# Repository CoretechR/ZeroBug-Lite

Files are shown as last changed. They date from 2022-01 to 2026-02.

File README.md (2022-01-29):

# ZeroBug Lite

Zerobug Lite is a minimalistic version of the ZeroBug Hexapod robot. By porting the microcontroller's features to Python, the robot can be fully controlled with only the Rasbperry Pi and an updated PCB.

This is a somewhat experimental build. Use at your own risk!

For CAD files, see the original project: https://github.com/CoretechR/ZeroBug

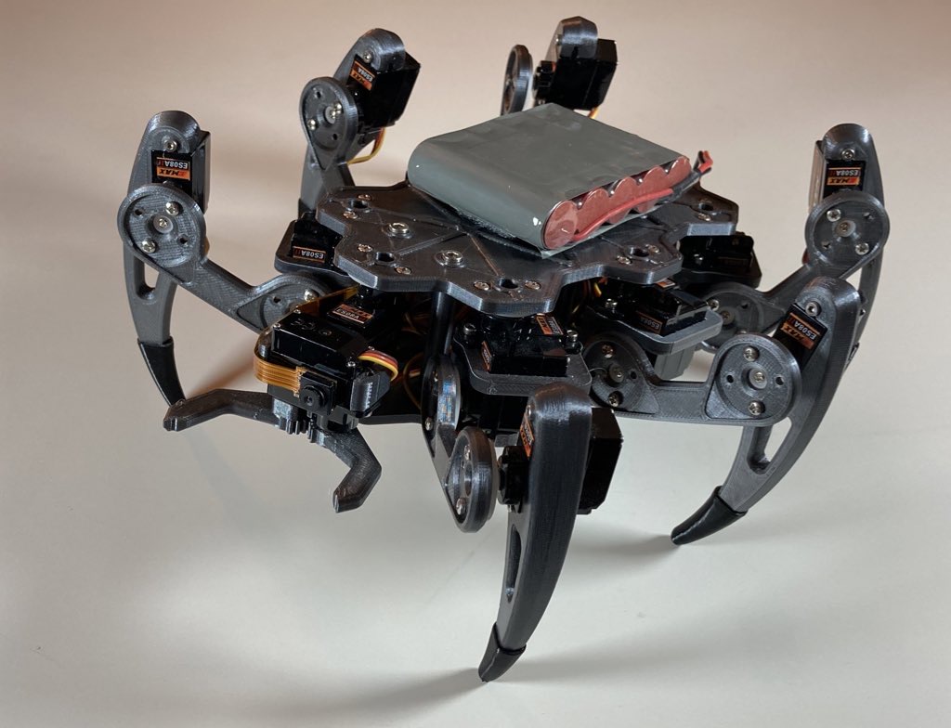
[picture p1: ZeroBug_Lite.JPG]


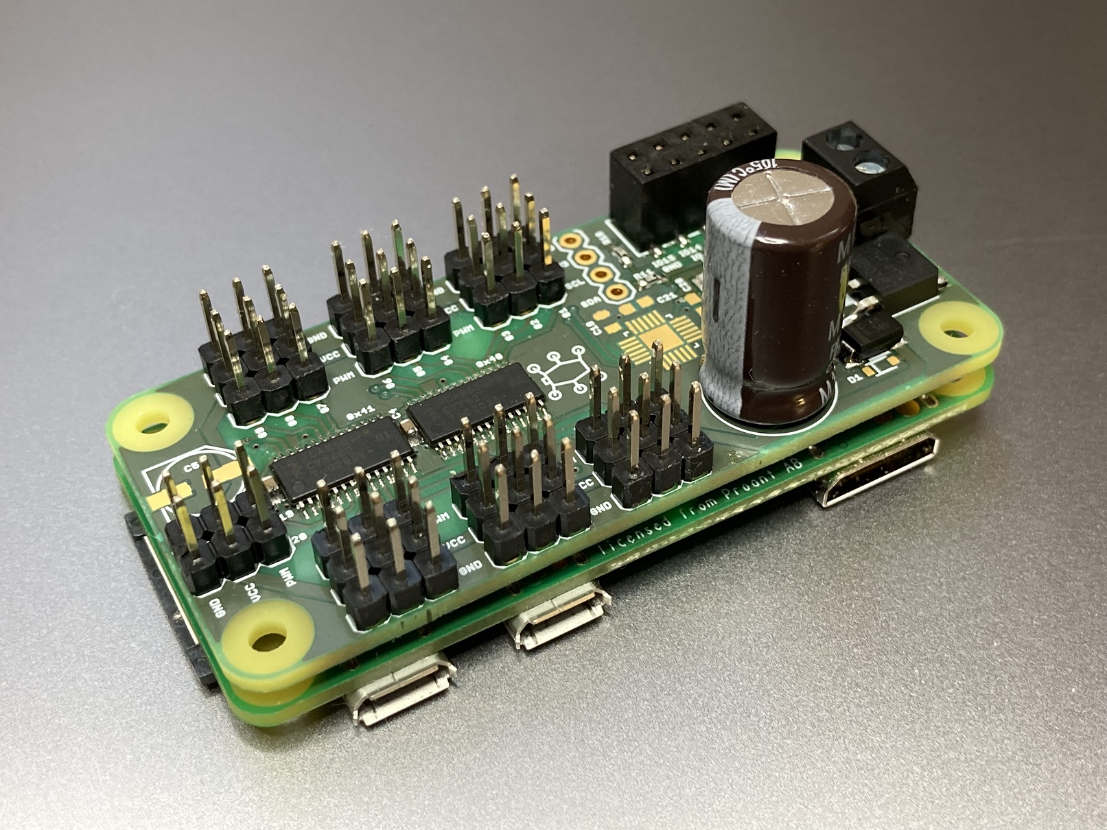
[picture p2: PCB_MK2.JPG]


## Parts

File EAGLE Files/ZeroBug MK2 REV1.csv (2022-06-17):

Qty | Value | Device | Package | Parts | Description | DATASHEET-URL | GENDER | IR | MPN | OC_FARNELL | OC_NEWARK | PACKAGE | PACKAGING | PART-NUMBER | PINS | PROD_ID | ROWS | SUPPLIER | TYPE | VALUE | WE-NUMBER
1 |  | 6103XX21821_61031021821 | 61031021821 | J23 | WR-PHD 2.54 mm SMT Dual Socket Header (Reel) | https://katalog.we-online.com/em/datasheet/61031021821.pdf | Socket Header | 3A |  |  |  |  | Tape and Reel with Cap | 61031021821 | 10 |  | Dual |  | Straight Type 2 |  | 61031021821
20 |  | CONN_03 | 1X03 | J3, J4, J5, J6, J7, J8, J9, J10, J11, J12, J13, J14, J15, J16, J17, J18, J19, J20, J21, J22 | Multi connection point. Often used as Generic Header-pin footprint for 0.1 inch spaced/style header connections |  |  |  |  |  |  |  |  |  |  | XXX-00000 |  |  |  | 455-1750-1-ND
1 |  | CPOL-USE5-10.5 | E5-10,5 | C6 | POLARIZED CAPACITOR, American symbol
2 |  | PCA9685 | TSSOP28 | U1, U2 | PCA9685 - 16 Channel 12-Bit I2C PWM Controller
1 |  | TERMBLOCK_1X2 | TERMBLOCK_1X2-3.5MM | J1 | 3.5mm Terminal block
2 | 0.1uF | 0.1UF-0603-25V-(+80/-20%) | 0603 | C20, C21 | 0.1µF ceramic capacitors |  |  |  |  |  |  |  |  |  |  | CAP-00810 |  |  |  | 0.1uF
1 | 1.0uF | 1.0UF-0805-25V-(+80/-20%) | 0805 | C2 | 1µF ceramic capacitors |  |  |  |  |  |  |  |  |  |  | CAP-11625 |  |  |  | 1.0uF
1 | 100uF | 100UF-POLAR-25V-20%(ELEC) | PANASONIC_D | C5 | 100µF polarized capacitors |  |  |  |  |  |  |  |  |  |  | CAP-12547 |  |  |  | 100uF
2 | 10k | 10KOHM-0603-1/10W-1% | 0603 | R10, R11 | 10kO resistor |  |  |  |  |  |  |  |  |  |  | RES-00824 |  |  |  | 10k
1 | 10nF | 47PF-0603-50V-5% | 0603 | C17 | 47pF ceramic capacitors |  |  |  |  |  |  |  |  |  |  | CAP-08913 |  |  |  | 47pF
2 | 10uF | 1.0UF-0805-25V-(+80/-20%) | 0805 | C1, C4 | 1µF ceramic capacitors |  |  |  |  |  |  |  |  |  |  | CAP-11625 |  |  |  | 1.0uF
1 | 1X4-BIG | 1X4-BIG | 1X04-BIG | CN1 | 4-pin connector
1 | 2.2uF | 1.0UF-0805-25V-(+80/-20%) | 0805 | C18 | 1µF ceramic capacitors |  |  |  |  |  |  |  |  |  |  | CAP-11625 |  |  |  | 1.0uF
1 | 4.7uF | 1.0UF-0805-25V-(+80/-20%) | 0805 | C3 | 1µF ceramic capacitors |  |  |  |  |  |  |  |  |  |  | CAP-11625 |  |  |  | 1.0uF
1 | AOD417 | MOSFET-PTO252 | TO252 | Q1 | P-Channel Mosfet
1 | BAT20J | DIODE-SCHOTTKY-BAT20J | SOD-323 | D1 | Schottky diodes in SFE's production catalog |  |  |  |  |  |  |  |  |  |  | DIO-11623 |  |  |  | BAT20J
1 | CDBA340L-HF | DIODE-DO-214AC | DO-214AC | D2 | DIODE
1 | MCP1826S-5002E/DB | MCP1825S-5002E/DB | SOT230P700X180-4N | U4 | IC, LDO, 5.0V, 500MA |  |  |  | MCP1825S-5002E/DB | 1578407 | 26M9964 | SOT-223-3 |  |  |  |  |  | Microchip
1 | MPU-6050-1 | MPU-6050-1 | QFN-24-4MM2 | U$2

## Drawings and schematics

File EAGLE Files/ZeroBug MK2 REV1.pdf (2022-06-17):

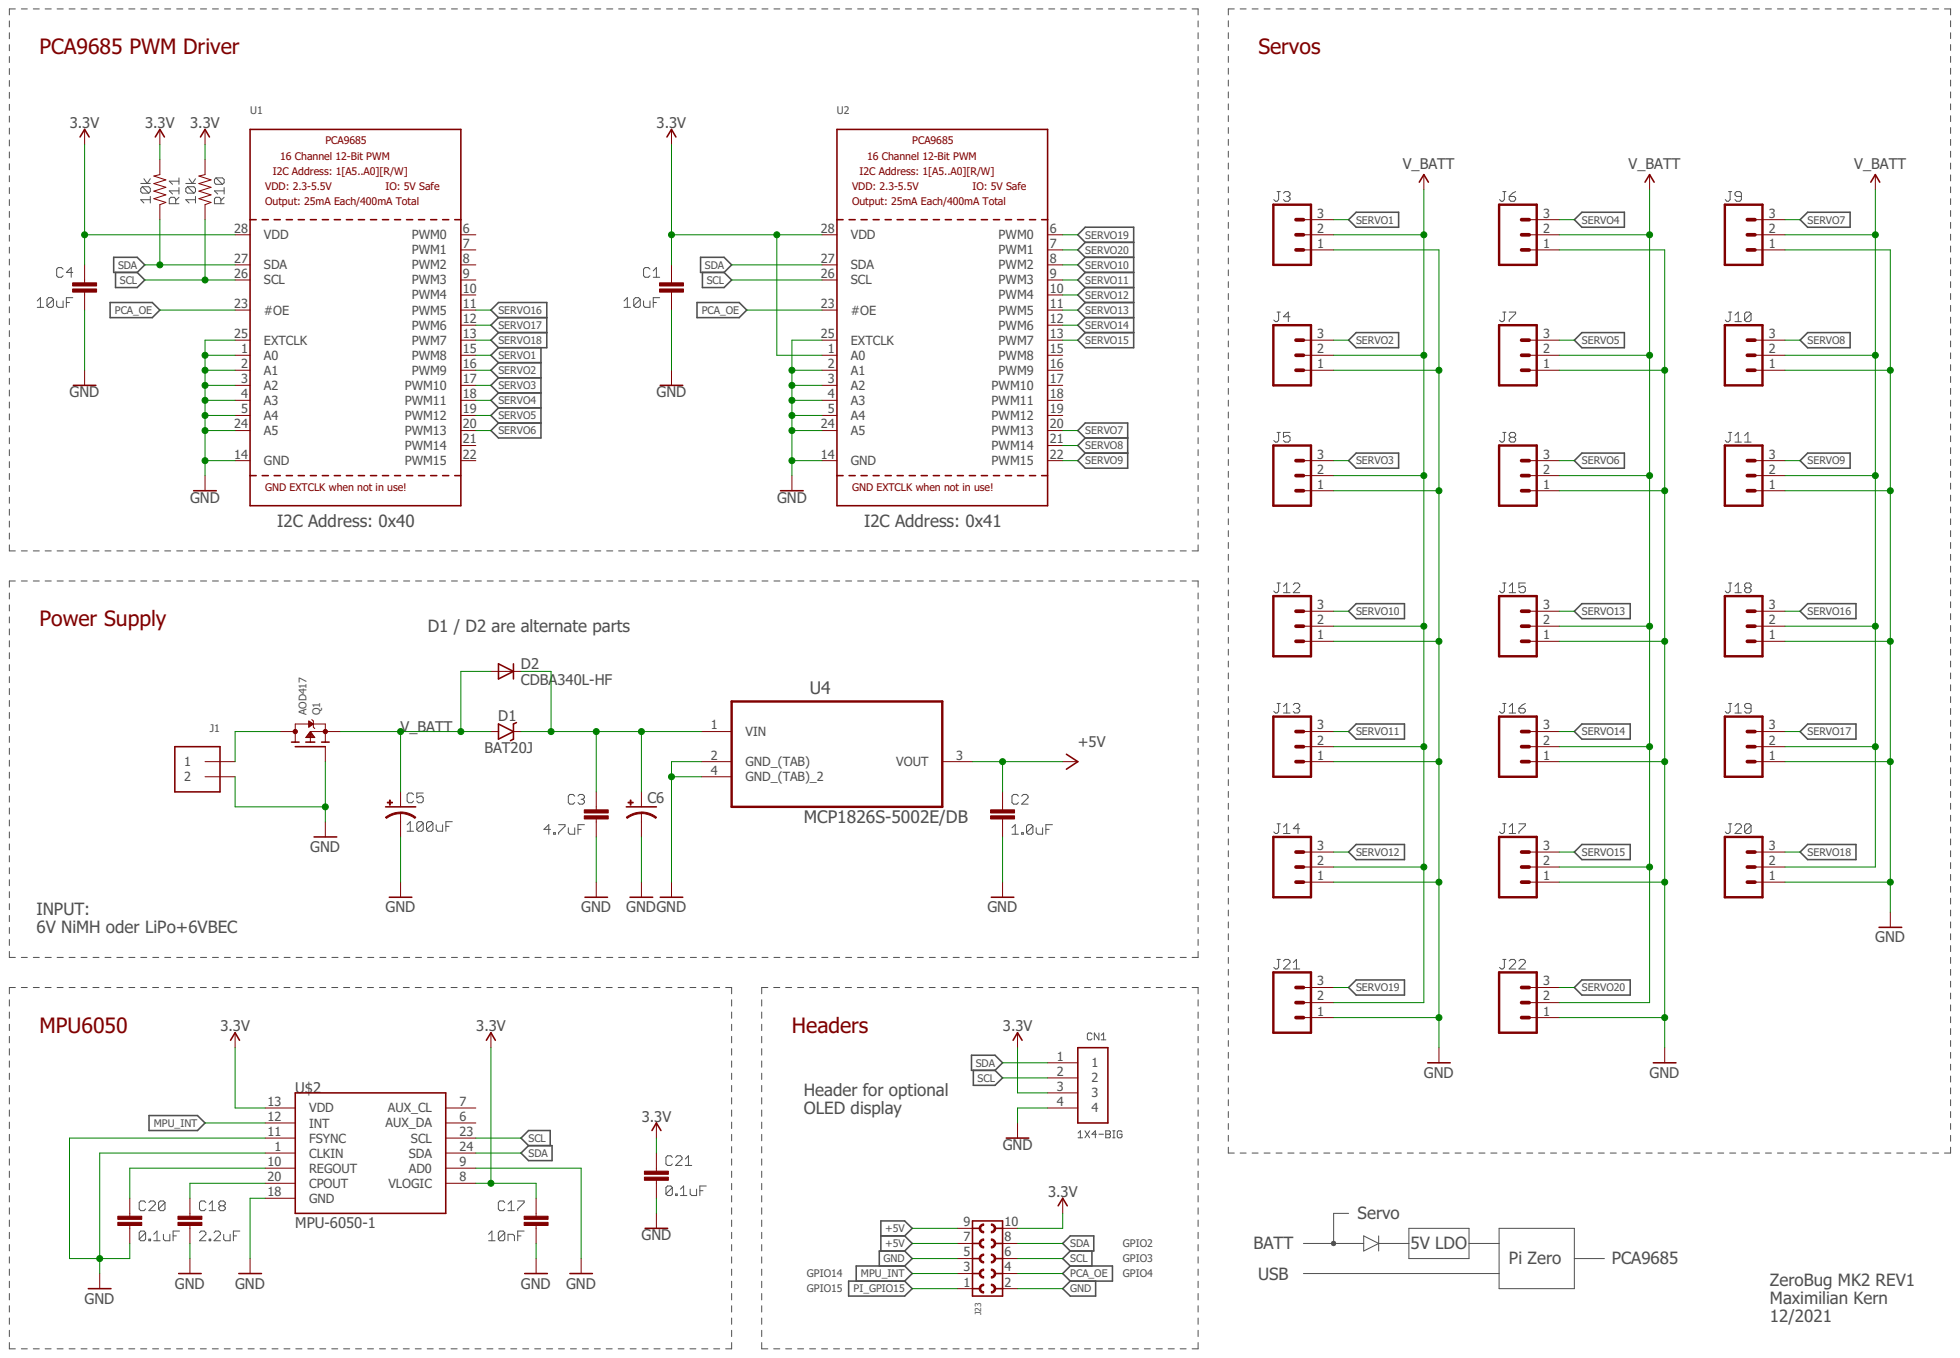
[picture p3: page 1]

GND EXTCLK when not in use!

INPUT: 6V NiMH oder LiPo+6VBEC

Pi Zero Servo BATT

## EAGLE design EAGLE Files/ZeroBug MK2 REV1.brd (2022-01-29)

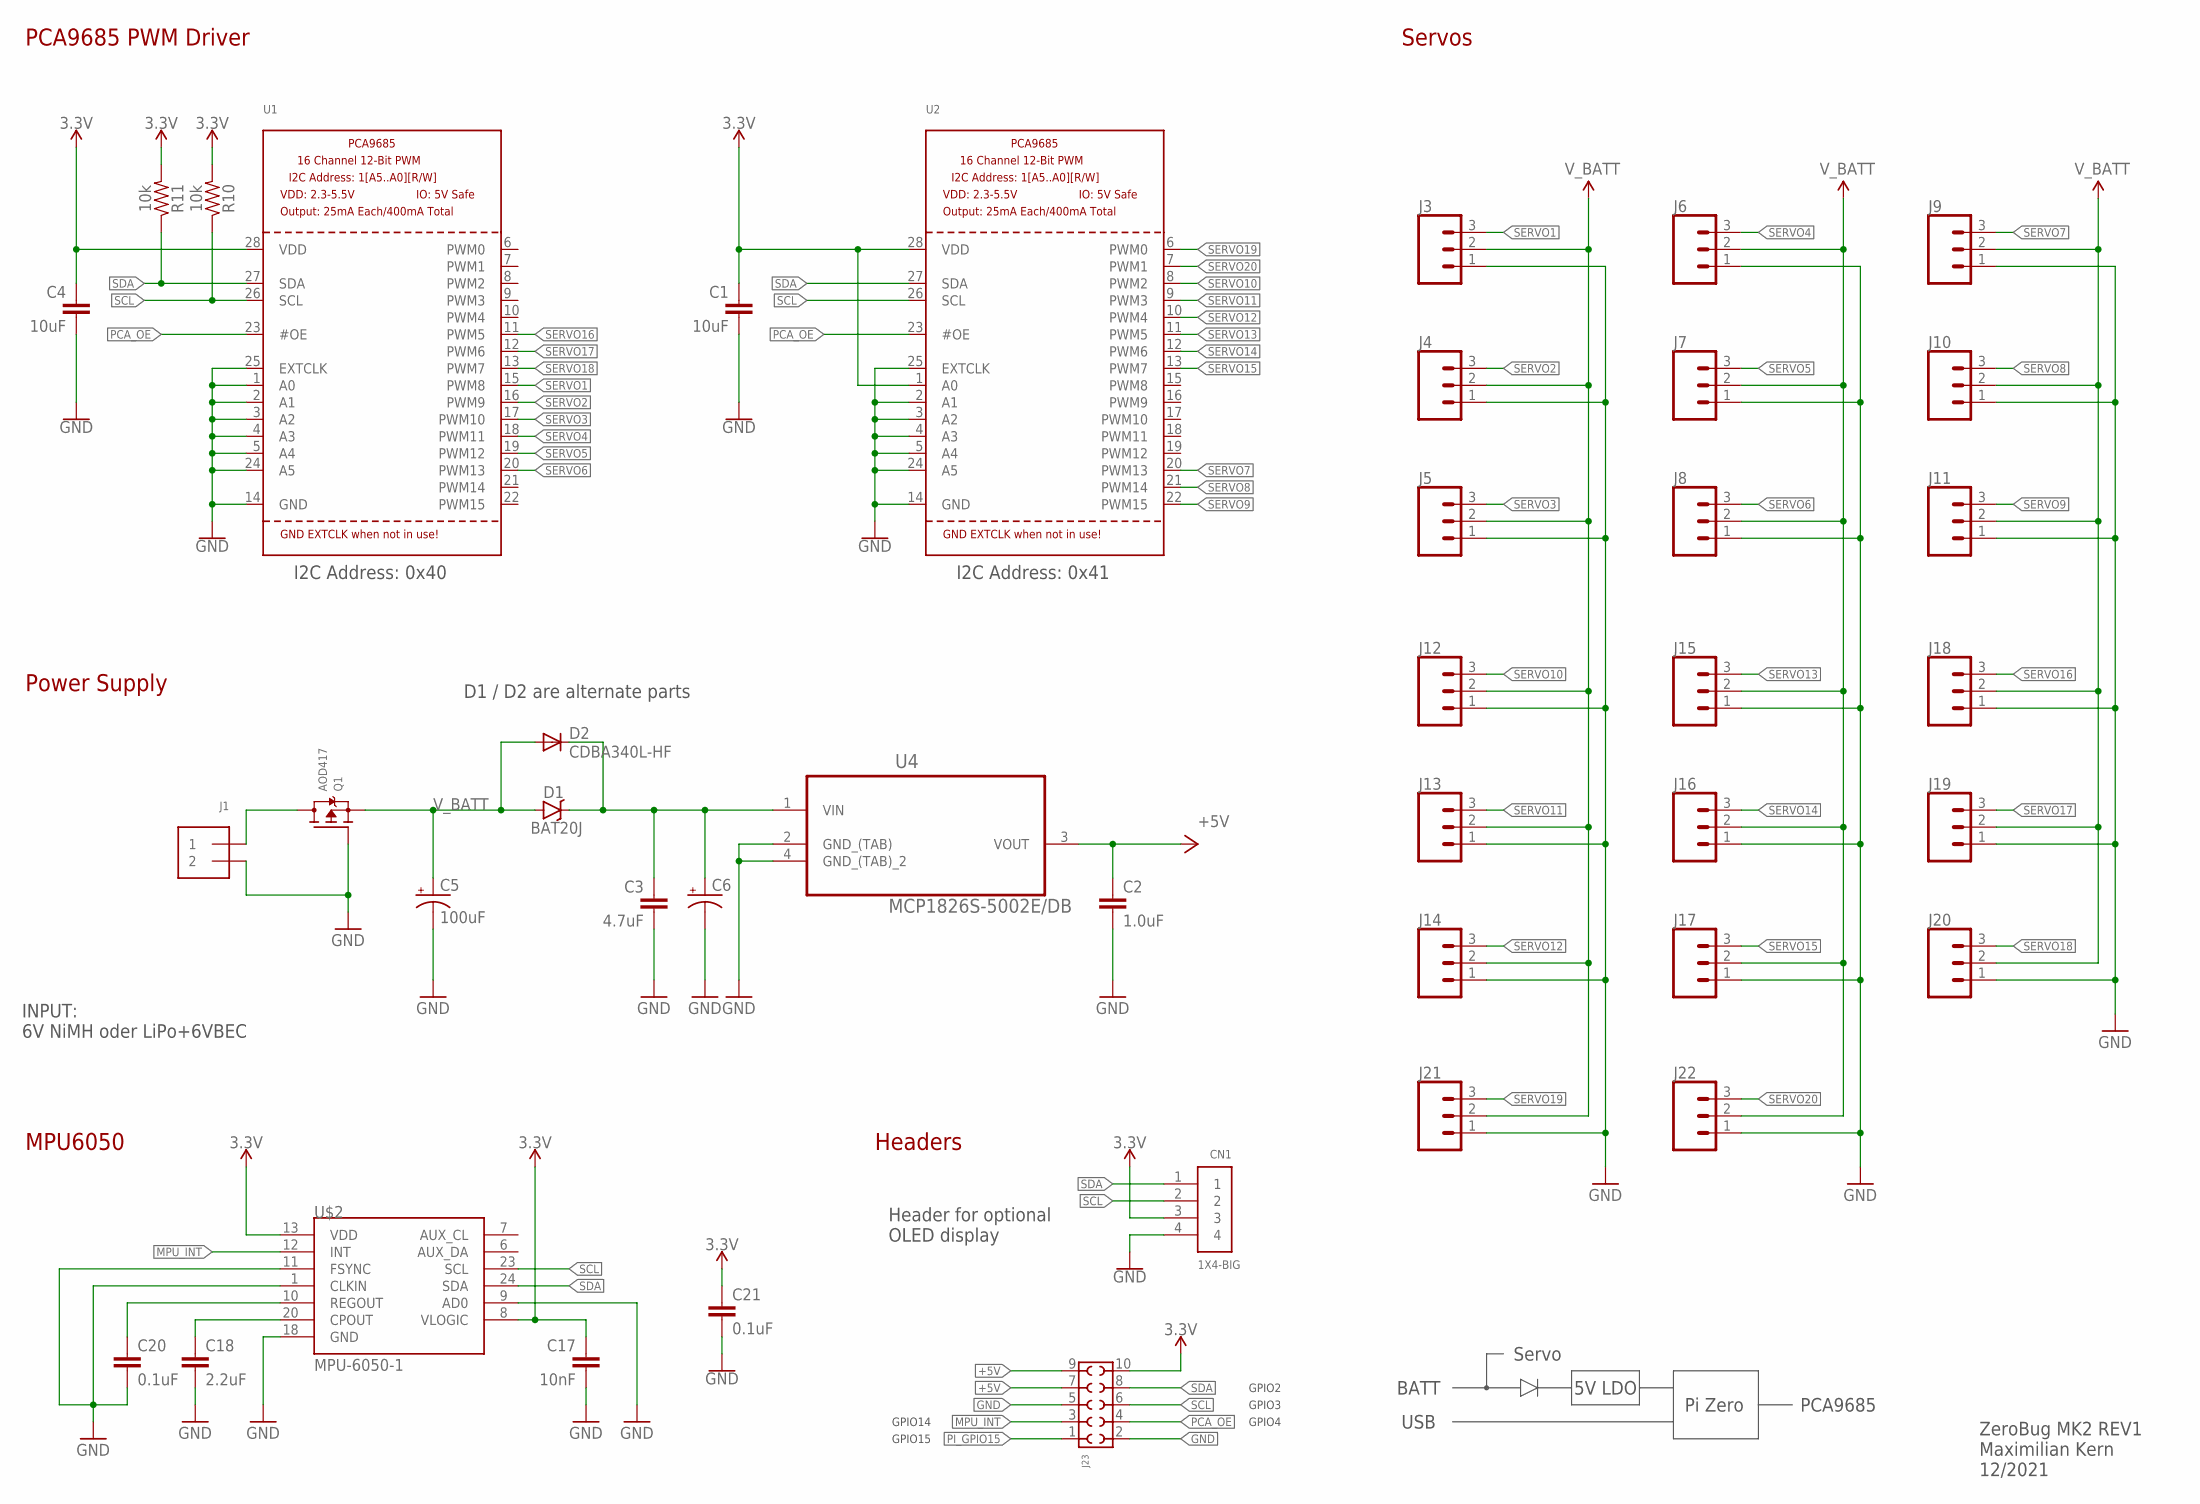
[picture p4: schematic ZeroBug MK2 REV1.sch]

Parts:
C1, C4: 10uF; 0805
C2: 1.0uF; 0805
C3: 4.7uF; 0805
C5: 100uF; PANASONIC_D
C6: CPOL-USE5-10.5; E5-10,5
C17: 10nF; 0603
C18: 2.2uF; 0805
C20, C21: 0.1uF; 0603
CN1: 1X4-BIG; 1X04-BIG
D1: BAT20J; SOD-323
D2: CDBA340L-HF; DO-214AC
J1: TERMBLOCK_1X2; TERMBLOCK_1X2-3.5MM
J3, J4, J5, J6, J7, J8, J9, J10, J11, J12, J13, J14, J15, J16, J17, J18, J19, J20, J21, J22: CONN_03; 1X03
J23: 6103XX21821_61031021821; 61031021821
Q1: AOD417; TO252
R10, R11: 10k; 0603
U1, U2: PCA9685; TSSOP28
U4: MCP1826S-5002E/DB; SOT230P700X180-4N
U$2: MPU-6050-1; QFN-24-4MM2

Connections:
3.3V: C1.1, C4.1, C17.1, C21.1, CN1.3, J23.10, R10.2, R11.2, U1.28 (VDD), U2.1 (A0), U2.28 (VDD), U$2.8 (VLOGIC), U$2.13 (VDD)
+5V: C2.1, J23.7, J23.9, U4.3 (VOUT)
GND: C1.2, C2.2, C3.2, C4.2, C5.-, C6.-, C17.2, C18.2, C20.2, C21.2, CN1.4, J1.2, J3.1, J4.1, J5.1, J6.1, J7.1, J8.1, J9.1, J10.1, J11.1, J12.1, J13.1, J14.1, J15.1, J16.1, J17.1, J18.1, J19.1, J20.1, J21.1, J22.1, J23.2, J23.5, Q1.1 (G), U1.1 (A0), U1.2 (A1), U1.3 (A2), U1.4 (A3), U1.5 (A4), U1.14 (GND), U1.24 (A5), U1.25 (EXTCLK), U2.2 (A1), U2.3 (A2), U2.4 (A3), U2.5 (A4), U2.14 (GND), U2.24 (A5), U2.25 (EXTCLK), U4.2 (GND_(TAB)), U4.4 (GND_(TAB)_2), U$2.1 (CLKIN), U$2.9 (AD0), U$2.11 (FSYNC), U$2.18 (GND)
MPU_INT: J23.3, U$2.12 (INT)
unnamed: C3.1, C6.+, D1.C, D2.C, U4.1 (VIN)
unnamed: J1.1, Q1.3 (D)
unnamed: C18.1, U$2.20 (CPOUT)
unnamed: C20.1, U$2.10 (REGOUT)
PCA_OE: J23.4, U1.23 (#OE), U2.23 (#OE)
PI_GPIO15: J23.1
SCL: CN1.2, J23.6, R10.1, U1.26 (SCL), U2.26 (SCL), U$2.23 (SCL)
SDA: CN1.1, J23.8, R11.1, U1.27 (SDA), U2.27 (SDA), U$2.24 (SDA)
SERVO1: J3.3, U1.15 (PWM8)
SERVO2: J4.3, U1.16 (PWM9)
SERVO3: J5.3, U1.17 (PWM10)
SERVO4: J6.3, U1.18 (PWM11)
SERVO5: J7.3, U1.19 (PWM12)
SERVO6: J8.3, U1.20 (PWM13)
SERVO7: J9.3, U2.20 (PWM13)
SERVO8: J10.3, U2.21 (PWM14)
SERVO9: J11.3, U2.22 (PWM15)
SERVO10: J12.3, U2.8 (PWM2)
SERVO11: J13.3, U2.9 (PWM3)
SERVO12: J14.3, U2.10 (PWM4)
SERVO13: J15.3, U2.11 (PWM5)
SERVO14: J16.3, U2.12 (PWM6)
SERVO15: J17.3, U2.13 (PWM7)
SERVO16: J18.3, U1.11 (PWM5)
SERVO17: J19.3, U1.12 (PWM6)
SERVO18: J20.3, U1.13 (PWM7)
SERVO19: J21.3, U2.6 (PWM0)
SERVO20: J22.3, U2.7 (PWM1)
V_BATT: C5.+, D1.A, D2.A, J3.2, J4.2, J5.2, J6.2, J7.2, J8.2, J9.2, J10.2, J11.2, J12.2, J13.2, J14.2, J15.2, J16.2, J17.2, J18.2, J19.2, J20.2, J21.2, J22.2, Q1.2 (S)

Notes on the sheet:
ZeroBug MK2 REV1 Maximilian Kern 12/2021
INPUT: 6V NiMH oder LiPo+6VBEC
5V LDO
Pi Zero
Servo
BATT
USB
PCA9685
MPU6050
Servos
PCA9685 PWM Driver
Headers
Power Supply
GPIO4
GPIO2
GPIO3
GPIO14
GPIO15
I2C Address: 0x40
I2C Address: 0x41
D1 / D2 are alternate parts
Header for optional OLED display

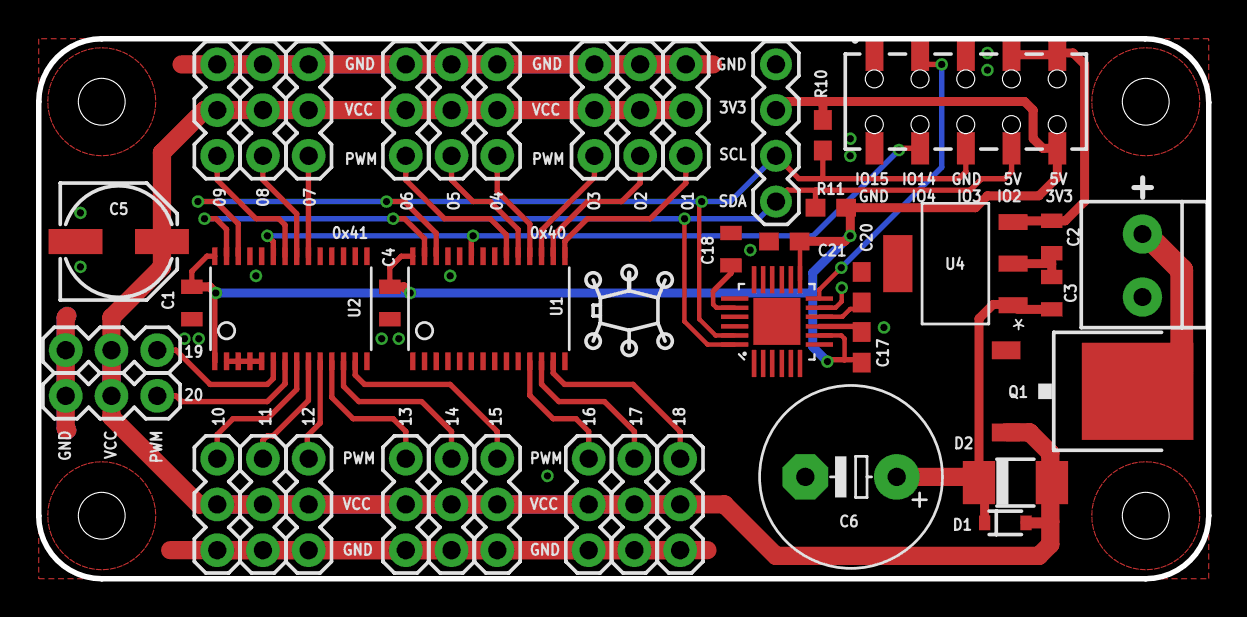
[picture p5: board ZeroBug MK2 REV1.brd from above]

Board: 2 copper layers, 65.0 x 30.0 mm, 42 parts (0 on the bottom side), 32 nets.

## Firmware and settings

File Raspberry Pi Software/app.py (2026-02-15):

from vector import *
from aiohttp import web
import socketio
import asyncio
from gpiozero import CPUTemperature
import pygame
import os
import math
import time
from board import SCL, SDA
import busio
import RPi.GPIO as GPIO

# Import the PCA9685 module.
from adafruit_motor import servo
from adafruit_pca9685 import PCA9685

# constants
SERVOMIN = 604.0 # This is the 'minimum' pulse length count (out of 4096)
SERVOMAX = 2260.0 # This is the 'maximum' pulse length count (out of 4096)
SERVO_FREQ = 50 # Analog servos run at ~50 Hz updates
PCA_OE = 4 # PCA Output Enable Pin

# global variables
powerup = False;
powerdown = False;

# Create the I2C bus interface.
i2c_bus = busio.I2C(SCL, SDA, frequency=400)

# Create a simple PCA9685 class instance.
pca_a = PCA9685(i2c_bus, address=0x40)
pca_b = PCA9685(i2c_bus, address=0x41)

# Set the PWM frequency to 50hz.
pca_a.frequency = SERVO_FREQ
pca_b.frequency = SERVO_FREQ
# Set twice because of some i2c error stuff
time.sleep(0.1);
pca_a.frequency = SERVO_FREQ
pca_b.frequency = SERVO_FREQ

clawOpen = False;
clawClose = False;
clawPos = 0.0;

servos = [None] * 20
servos[0] = servo.Servo(pca_a.channels[8],  actuation_range = 300, min_pulse=SERVOMIN, max_pulse=SERVOMAX)
servos[1] = servo.Servo(pca_a.channels[9],  actuation_range = 300, min_pulse=SERVOMIN, max_pulse=SERVOMAX)
servos[2] = servo.Servo(pca_a.channels[10], actuation_range = 300, min_pulse=SERVOMIN, max_pulse=SERVOMAX)

servos[3] = servo.Servo(pca_a.channels[11],  actuation_range = 300, min_pulse=SERVOMIN, max_pulse=SERVOMAX)
servos[4] = servo.Servo(pca_a.channels[12],  actuation_range = 300, min_pulse=SERVOMIN, max_pulse=SERVOMAX)
servos[5] = servo.Servo(pca_a.channels[13], actuation_range = 300, min_pulse=SERVOMIN, max_pulse=SERVOMAX)

servos[6] = servo.Servo(pca_b.channels[13],  actuation_range = 300, min_pulse=SERVOMIN, max_pulse=SERVOMAX)
servos[7] = servo.Servo(pca_b.channels[14],  actuation_range = 300, min_pulse=SERVOMIN, max_pulse=SERVOMAX)
servos[8] = servo.Servo(pca_b.channels[15], actuation_range = 300, min_pulse=SERVOMIN, max_pulse=SERVOMAX)

servos[9] = servo.Servo(pca_b.channels[2],  actuation_range = 300, min_pulse=SERVOMIN, max_pulse=SERVOMAX)
servos[10] = servo.Servo(pca_b.channels[3],  actuation_range = 300, min_pulse=SERVOMIN, max_pulse=SERVOMAX)
servos[11] = servo.Servo(pca_b.channels[4], actuation_range = 300, min_pulse=SERVOMIN, max_pulse=SERVOMAX)

servos[12] = servo.Servo(pca_b.channels[5],  actuation_range = 300, min_pulse=SERVOMIN, max_pulse=SERVOMAX)
servos[13] = servo.Servo(pca_b.channels[6],  actuation_range = 300, min_pulse=SERVOMIN, max_pulse=SERVOMAX)
servos[14] = servo.Servo(pca_b.channels[7], actuation_range = 300, min_pulse=SERVOMIN, max_pulse=SERVOMAX)

servos[15] = servo.Servo(pca_a.channels[5],  actuation_range = 300, min_pulse=SERVOMIN, max_pulse=SERVOMAX)
servos[16] = servo.Servo(pca_a.channels[6],  actuation_range = 300, min_pulse=SERVOMIN, max_pulse=SERVOMAX)
servos[17] = servo.Servo(pca_a.channels[7], actuation_range = 300, min_pulse=SERVOMIN, max_pulse=SERVOMAX)

servos[18] = servo.Servo(pca_b.channels[0],  actuation_range = 300, min_pulse=SERVOMIN, max_pulse=SERVOMAX)
servos[19] = servo.Servo(pca_b.channels[1], actuation_range = 300, min_pulse=SERVOMIN, max_pulse=SERVOMAX)


# Initialize routines
sio = socketio.AsyncServer()
app = web.Application()
sio.attach(app)
loop = asyncio.get_event_loop()
pygame.display.init()

# enable PCA (LOW means On)
GPIO.setmode(GPIO.BCM)
GPIO.setup(PCA_OE, GPIO.OUT)
GPIO.output(PCA_OE, GPIO.LOW)

# setup hexapod parameters
tripodGait = [[0 for x in range(6)] for y in range(120)] 
waveGait = [[0 for x in range(6)] for y in range(120)] 

Hex = gaitEngine()

jX = 0  # (Joystick) Walking X, Y and Rotate
jY = 0
jR = 0

# tripod gait    
Hex.gaitSpeed = 1.0
Hex.legSpeed = 1.0
tripodGait[0][0]  = 1
tripodGait[0][2]  = 1
tripodGait[0][4]  = 1
    
tripodGait[30][1] = 1
tripodGait[30][3] = 1
tripodGait[30][5] = 1
    
tripodGait[60][0] = 1
tripodGait[60][2] = 1
tripodGait[60][4] = 1
    
tripodGait[90][1] = 1
tripodGait[90][3] = 1
tripodGait[90][5] = 1  
    
# wave gait
#Hex.gaitSpeed = 2.0
#Hex.legSpeed = 0.7
waveGait[00][0]  = 1
waveGait[20][4]  = 1
waveGait[40][2]  = 1
waveGait[60][5]  = 1
waveGait[80][1]  = 1
waveGait[100][3] = 1


    
async def controlLoop():
    while True:
        global Hex, powerup, powerdown, clawPos, clawOpen, clawClose, SERVOMIN, SERVOMAX, servos
        IKError = False;
        
        if powerup == True:
            if(Hex.traZ > 0):
                Hex.legS[0].setto(-70, -85, 0)
                Hex.legS[1].setto(-90, 0, 0)
                Hex.legS[2].setto(-70, 85, 0)
                Hex.legS[3].setto(70, 85, 0)
                Hex.legS[4].setto(90, 0, 0)
                Hex.legS[5].setto(70, -85, 0)
                Hex.traZ -= 0.3
            else:     
                powerup = False;               
        elif powerdown == True:
            if(Hex.traZ < 26):
                Hex.legS[0].setto(-65, -70, 0)
                Hex.legS[1].setto(-80, 0, 0)
                Hex.legS[2].setto(-65, 70, 0)
                Hex.legS[3].setto(65, 70, 0)
                Hex.legS[4].setto(80, 0, 0)
                Hex.legS[5].setto(65, -70, 0)
                Hex.traZ += 0.3
            else:
                powerdown = False
        
        clawPos = constrain(clawPos, 0, 67)
        if(clawOpen):
            if(clawPos > 0):
                clawPos -= 2
            else:
                clawOpen = False;
        elif(clawClose):
            if(clawPos < 58):
                clawPos += 2
            else:
                clawClose = False
        
        # Configure and run the hexapod engine
        Hex.gSeq = waveGait
        Hex.walkX = jX
        Hex.walkY = jY
        Hex.walkR = jR
        Hex.gaitStep()
        Hex.runBodyIK()
        IKError = (Hex.runLegIK() != 0)
        
        # servo angle constraints
        angleA = constrain( Hex.legAngle[0][0]*180/PI, -65, 65);
        angleB = constrain(-Hex.legAngle[0][1]*180/PI, -100, 100);
        angleC = constrain( Hex.legAngle[0][2]*180/PI, -100, 100);
        angleD = constrain( Hex.legAngle[1][0]*180/PI, -65, 65);
        angleE = constrain(-Hex.legAngle[1][1]*180/PI, -100, 100);
        angleF = constrain( Hex.legAngle[1][2]*180/PI, -100, 100);
        angleG = constrain( Hex.legAngle[2][0]*180/PI, -65, 65);
        angleH = constrain(-Hex.legAngle[2][1]*180/PI, -100, 100);
        angleI = constrain( Hex.legAngle[2][2]*180/PI, -100, 100);
        
        angleJ = constrain( Hex.legAngle[3][0]*180/PI, -65, 65);  
        angleK = constrain( Hex.legAngle[3][1]*180/PI, -100, 100);
        angleL = constrain(-Hex.legAngle[3][2]*180/PI, -100, 100);
        angleM = constrain( Hex.legAngle[4][0]*180/PI, -65, 65);
        angleN = constrain( Hex.legAngle[4][1]*180/PI, -100, 100);
        angleO = constrain(-Hex.legAngle[4][2]*180/PI, -100, 100);
        angleP = constrain( Hex.legAngle[5][0]*180/PI, -65, 65);
        angleQ = constrain( Hex.legAngle[5][1]*180/PI, -100, 100);
        angleR = constrain(-Hex.legAngle[5][2]*180/PI, -100, 100);
        
        angleS = constrain(Hex.rotZ*180/PI*1.7, -65, 65);
        angleT = constrain(clawPos, 0, 67);
        
        # servo angle offsets
        angleA += -24;
        angleB += 18;
        angleC += 3;
        
        angleD += 14;
        angleE += 2;
        angleF += 0;
        
        angleG += 50;
        angleH += -12;
        angleI += -1;
       
        #---
        
        angleJ += -35;
        angleK += 11;
        angleL += 6;
        
        angleM += 3;
        angleN += 12;
        angleO += -6;
        
        angleP += 23;
        angleQ += 0;
        angleR += 0;
        
        angleS += -8;
        angleT += 0;
        
        
        #print(angleA)
        
        # servo angle mapping
        servos[0].angle = angleA + 90;
        servos[1].angle = angleB + 120;
        servos[2].angle = angleC + 120;
        
        
        servos[3].angle = angleD + 90;
        servos[4].angle = angleE + 120;
        servos[5].angle = angleF + 120;
        
        
        servos[6].angle = angleG + 90;
        servos[7].angle = angleH + 120;
        servos[8].angle = angleI + 120;
        
        servos[9].angle = angleJ + 90;
        servos[10].angle = angleK + 120;
        servos[11].angle = angleL + 120;
        
        servos[12].angle = angleM + 90;
        servos[13].angle = angleN + 120;
        servos[14].angle = angleO + 120;
        
        servos[15].angle = angleP + 90;
        servos[16].angle = angleQ + 120;
        servos[17].angle = angleR + 120;
        
        servos[18].angle = angleS + 120;
        servos[19].angle = angleT + 120;
        
        
        
        
        #pca_a.channels[8].duty_cycle = 0x0000
        #pca_b.channels[0].duty_cycle = 0x0000
        #time.sleep(1)
        #pca_a.channels[8].duty_cycle = 0x7FFF
        #pca_b.channels[0].duty_cycle = 0x3000
        #time.sleep(1)
        
        await asyncio.sleep(0.001) # gait engine loop speed

async def gameLoop():
    global Hex, powerup, powerdown, clawClose, clawOpen, clawPos
    while True:
        try:
            pygame.joystick.init()
            # Check if there is a joystick
            if(pygame.joystick.get_count()) < 1:   
                pygame.joystick.quit()
                await asyncio.sleep(1) 
            else:   
                joystick = pygame.joystick.Joystick(0)
                break
        except pygame.error:
            pygame.joystick.quit()
            await asyncio.sleep(1) 
    while True:       
        try:
            await asyncio.sleep(0.01)
            joystick.init()

            if joystick.get_button(6):
                clawPos += 1
            if joystick.get_button(7):
                clawPos -= 1
            if joystick.get_hat(0)[1] == 1:
                Hex.traX = 0
                Hex.traY = 0
                Hex.traZ = -0.3
            if joystick.get_hat(0)[1] == -1:
                Hex.traX = 0
                Hex.traY = 0
                Hex.traZ = 0.3
                
                
            # Check for events
            for event in pygame.event.get():
                if event.type == pygame.JOYBUTTONDOWN:	
                    if joystick.get_button(3):
                        powerdown = True;
                    elif joystick.get_button(4):
                        powerup = True;
                    elif joystick.get_button(15):
                        Hex.gaitSpeed = 1.0
                        Hex.legSpeed = 1.0
                        Hex.gSeq = list(tripodGait)        
                    elif joystick.get_button(11):
                        Hex.gaitSpeed = 2.0
                        Hex.legSpeed = 1.3
                        Hex.gSeq = list(waveGait)                        
                    elif joystick.get_button(0):
                        clawClose = True
                    elif joystick.get_button(1):
                        clawOpen = True
                        
                if event.type == pygame.JOYAXISMOTION:                        
                    axis0 = joystick.get_axis(0)
                    axis1 = joystick.get_axis(1)
                    axis2 = joystick.get_axis(2)
                    axis3 = joystick.get_axis(3)
                    axis4 = (joystick.get_axis(4) -joystick.get_axis(5))/2

                    jX = axis0*0.7
                    jY = -axis1*1.2
                    jR = axis4*0.8
                    Hex.TraZ = axis2/5
                    Hex.TraY = axis3/4
                    
                # Multiple events are generated for the same axis motion, so break after the first
                break
        except pygame.error:
            await asyncio.sleep(1) 

loop = asyncio.get_event_loop()
loop.create_task(gameLoop())

serialLoop = asyncio.get_event_loop()
serialLoop.create_task(controlLoop())

def index(request):
    with open(os.path.dirname(__file__)+'/index.html') as f:
        return web.Response(text=f.read(), content_type='text/html')

async def sendTemp():
    while True:
        await asyncio.sleep(3)
        await sio.emit('temp', CPUTemperature().temperature)

loop.create_task(sendTemp())

async def heartbeat():
    while True:
        #print('heartbeat')
        await asyncio.sleep(1)

loop.create_task(heartbeat())

@sio.on('connect')
def chat_connection(sid, message):
    print('---- connected ----')
    
    
@sio.on('disconnect')
def chat_disconnect(sid):
    print('---- disconnected ----')

@sio.on('mov')
async def position(sid, msx, msy, msr):
    global jX, jY, jR
    msxString = "{:7.3f}".format(float(msx))
    msyString = "{:7.3f}".format(float(-msy))
    msrString = "{:7.3f}".format(float(msr))
    #print('m %s %s %s'%("000.000",msyString,msrString))
    jX = float(msxString)
    jY = float(msyString)
    jR = float(msrString)
    await asyncio.sleep(0.005)
    
@sio.on('rot')
async def position(sid, yaw, pitch, roll):
    global Hex
    yawString = "{:7.3f}".format(float(yaw/6))
    pitchString = "{:7.3f}".format(float(pitch/6))
    rollString = "{:7.3f}".format(float(roll/6))
    #print('r %s %s %s'%(rollString, pitchString, yawString))
    Hex.rotX = float(rollString)
    Hex.rotY = float(pitchString)
    Hex.rotZ = float(yawString)
    await asyncio.sleep(0.005)

@sio.on('pos')
async def position(sid, message):
    global powerup, powerdown
    if message == 1:
        powerup = True
    if message == 0:
        powerdown = True
    await asyncio.sleep(0.005)
        
@sio.on('gait')
async def position(sid, message):
    if message == 1:
        Hex.gaitSpeed = 1.0
        Hex.legSpeed = 1.0
        Hex.gSeq = list(tripodGait)
    elif message == 0:
        Hex.gaitSpeed = 2.0
        Hex.legSpeed = 1.3
        Hex.gSeq = list(waveGait)
    await asyncio.sleep(0.005)
    
@sio.on('claw')
async def position(sid, message):
    global clawOpen, clawClose
    if message == 1:
        clawClose = True
    elif message == 0:
        clawOpen = True
    await asyncio.sleep(0.005)

@sio.on('power')
async def position(sid, message):
    if message == 1:
        print('Shutting down...')
        os.system("sudo shutdown -h now") 

app.router.add_get('/', index)

if __name__ == '__main__':
    web.run_app(app, host='0.0.0.0', port=3000)
    loop.run_forever()
    serialLoop.run_forever()

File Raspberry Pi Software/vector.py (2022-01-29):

import math

def constrain(val, min_val, max_val):
    return min(max_val, max(min_val, val))

def mapp(x, in_min, in_max, out_min, out_max):
    return (x - in_min) * (out_max - out_min) / (in_max - in_min) + out_min

def sq(val):
    return (val*val)

def sin(val):
    return math.sin(val)

def cos(val):
    return math.cos(val)

def sqrt(val):
    return math.sqrt(val)

def atan(val):
    return math.atan(val)

def acos(val):
    return math.acos(constrain(val, -1, 1))

PI = math.pi



class gaitEngine(object):

    # public:
    gaitStepN = 0
    gSeq = [[0 for x in range(6)] for y in range(120)]
    legMoving = [0]*6
    gaitSpeed = 1.0 #  control gait speed by adjusting gaitStepN progression
    legSpeed = 1.0 #  control gait speed by adjusting leg lift function
    stepHeight = 20
    targetDeadZone = 3 #  allow off center leg position
    walkX = 0 #  inputs for walking in X,Y and rotation
    walkY = 0
    walkR = 0
    traX = float() # current body translation
    traY = float()
    traZ = float()
    rotX = float() # current for body rotation
    rotY = float()
    rotZ = float()
    #  hexapod constants
    coxa = int(11.6)
    femur = 44
    tibia = 69
    
    coxaPos = [] #  body position
    leg = [] # current leg positions (without body translation/rotation)
    legS = [] # defaulegT leg positions
    legT = [] # target leg positions
    legIK = [] # leg positions for body translation/rotation
    
    legAngle = [[0 for x in range(3)] for y in range(6)]

    def __init__(self): # Initialization
        
        for i in range(0, 6):
            self.coxaPos.append(vector())
            self.leg.append(vector())
            self.legS.append(vector())
            self.legT.append(vector())
            self.legIK.append(vector())
            self.coxaPos.append(vector())
            
        self.leg[0].setto(-70, -85, 0)
        self.leg[1].setto(-90, 0, 0)
        self.leg[2].setto(-70, 85, 0)
        self.leg[3].setto(70, 85, 0)
        self.leg[4].setto(90, 0, 0)
        self.leg[5].setto(70, -85, 0)
        
        for i in range(0, 6):
            self.legS[i]._setto(self.leg[i])
            self.legT[i]._setto(self.leg[i])
                
        bodyHeight = 40
        self.coxaPos[0].setto(-28, -48, bodyHeight)
        self.coxaPos[1].setto(-35, 0, bodyHeight)
        self.coxaPos[2].setto(-28, 48, bodyHeight)
        self.coxaPos[3].setto(28, 48, bodyHeight)
        self.coxaPos[4].setto(35, 0, bodyHeight)
        self.coxaPos[5].setto(28, -48, bodyHeight)

    def gaitStep(self):
        
        self.walkX = constrain(self.walkX, -0.8, 0.8)
        self.walkY = constrain(self.walkY, -0.6, 0.6)
        self.walkR = constrain(self.walkR, -0.6, 0.6)
        
        self.gaitStepN += self.gaitSpeed
        gSeqLength = len(self.gSeq)
        if self.gaitStepN >= gSeqLength: self.gaitStepN = 0
        
        # calculate rotation and translation of legs over ground  
        s = sin(-self.walkR / 100)
        c = cos(-self.walkR / 100)
        
        # move legs with ground
        for i in range(0, 6):
            if self.leg[i].z == 0:
                self.leg[i].x = (self.leg[i].x * c - self.leg[i].y * s) - self.walkX
                self.leg[i].y = (self.leg[i].y * c + self.leg[i].x * s) + self.walkY
                # move target within boundary to allow some movement without stepping 
                if self.leg[i].z == 0 and sqrt(sq(self.leg[i].x - self.legS[i].x) + sq(self.leg[i].y - self.legS[i].y)) < self.targetDeadZone:
                    self.legT[i].x = self.leg[i].x
                    self.legT[i].y = self.leg[i].y
                else: # reset target when getting to far off center
                    self.legT[i]._setto(self.legS[i])
                    
        # if leg's turn in sequence AND if not on target AND not already moving
        # TODO: Do not rely on rounding gaitStepN to match the sequence in gSeq
        for legN in range (0, 6):
            if self.gSeq[int(self.gaitStepN)][legN] == 1 and not self.leg[legN].equalegS(self.legT[legN]) and self.legMoving[legN] == 0:
                #println("gaitStepN: " + self.gaitStepN + " legN: " + self.legN)
                self.leg[legN].xt = self.legS[legN].x
                self.leg[legN].yt = self.legS[legN].y
                self.leg[legN].xs = self.leg[legN].x
                self.leg[legN].ys = self.leg[legN].y
                self.legMoving[legN] = 1
            
            # if leg ist already moving
            if self.legMoving[legN] == 1:
                distanceLeft = self.leg[legN].move2D(self.legSpeed); 
                #self.leg[legN].z = self.legS[legN].z + self.stepHeight-self.stepHeight*sq(2*distanceLeft-1) # quadratic function leg lift
                self.leg[legN].z = self.legS[legN].z + self.stepHeight / 2 * (sin(2 * PI * (distanceLeft - 0.25)) + 1) # smoother sinus leg lift
                if self.leg[legN].z == 0:
                    self.legMoving[legN] = 0

    # Body Translation/Rotation
    def runBodyIK(self):

        self.traX = constrain(self.traX, -40, 40)
        self.traY = constrain(self.traY, -40, 40)
        self.traZ = constrain(self.traZ, -40, 40)
        
        self.rotX = constrain(self.rotX, -0.3, 0.3)
        self.rotY = constrain(self.rotY, -0.25, 0.25)
        self.rotZ = constrain(self.rotZ, -0.25, 0.25)
        
        for i in range(0, 6):
            self.legIK[i].x = self.leg[i].x * cos(self.rotZ) * cos(self.rotX) - self.leg[i].z * cos(self.rotZ) * sin(self.rotX) + self.leg[i].y * sin(self.rotZ) + self.traX
            self.legIK[i].y = self.leg[i].x * (sin(self.rotY) * sin(self.rotX) - cos(self.rotY) * sin(self.rotZ) * cos(self.rotX)) + self.leg[i].z * (cos(self.rotY) * sin(self.rotZ) * sin(self.rotX) + sin(self.rotY) * cos(self.rotX)) + self.leg[i].y * cos(self.rotY) * cos(self.rotZ) + self.traY
            self.legIK[i].z = self.leg[i].x * (sin(self.rotY) * sin(self.rotZ) * cos(self.rotX) + cos(self.rotY) * sin(self.rotX)) + self.leg[i].z * (sin(self.rotY) * sin(self.rotZ) * sin(self.rotX) + cos(self.rotY) * cos(self.rotX)) - self.leg[i].y * sin(self.rotY) * cos(self.rotZ) + self.traZ
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

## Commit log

2022-06-17 BOM added
    [ZeroBug MK2 REV1.csv]
2026-02-15 removed debug line
    - fixed debug line that caused robot to walk in y-direction by itself
    - System shutdown command should work now
    [app.py]

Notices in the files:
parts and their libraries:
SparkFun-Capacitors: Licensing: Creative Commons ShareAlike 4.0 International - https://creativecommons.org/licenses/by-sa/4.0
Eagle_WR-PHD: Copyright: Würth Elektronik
